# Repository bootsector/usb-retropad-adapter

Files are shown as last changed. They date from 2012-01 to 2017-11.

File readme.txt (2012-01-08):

USB RetroPad Adapter
(c)2011/2012 - Bruno Freitas - bootsector@ig.com.br
See COPYING.TXT for licensing information.

About
-----

USB RetroPad Adapter is a USB port of the Wii RetroPad Adapter. It allows you
to use the following classic controllers in your PC, Mac or PS3:

:. Sega Genesis pad(also supports: Sega Master System, Atari 2600 and others)

:. Nintendo NES pad

:. Super NES pad 

:. Playstation digital pads and Playstation 2 pads

:. Game Cube pad

:. Nintendo 64 pad

USB RetroPad Adapter also comes with handy screw terminal connectors, allowing
you to hook up a homemade arcade control to it and and use it to play your favo-
rite games on your PC or PS3!

How to get it
-------------

USB RetroPad Adapter is Opensource / Open hardware, so you can construct your
PCB, compile the source code, burn the firmware in the micro-controller and
start using it. 

However, there are people who are not familiar with PCB manufacturing process
nor have the skills, or even time, to construct his/her own adapter. For those
people, you are invited to contact me at bootsector@ig.com.br so I can sell
you a ready-to-use adapter! :)

You will also be able to buy it from both http://www.brunofreitas.com/ or
http://www.faiscaefumaca.com.br/

Legal
-----

USB RetroPad Adapter source code (software) is licensed under GPLv3.

USB RetroPad Adapter is open hardware licenced under Creative Commons 
Attribution-ShareAlike 3.0 Unported License. 

Acknowledgements
----------------

Thanks goes out to all people below. Without their work, this project wouldn't
be possible:

:. Roberto Oliveira for all the help with the PCB and "hardware" stuff.

:. Bill Porter for his PS2X Arduino library

:. The Arduino Team

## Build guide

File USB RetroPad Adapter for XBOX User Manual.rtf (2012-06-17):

USB RetroPad Adapter v1.1b for XBOX
User Manual Rev. 1.0 – 06/17/2012

About the USB RetroPad Adapter
USB RetroPad Adapter is an USB joystick adapter that allows you to use the following classic controllers with your PC, Mac and PS3 through the USB port or with your classic XBOX console using an XBOX controller port to USB adapter, with the newly released USB RetroPad Adapter for XBOX:
:. Sega Genesis pad (also supports: Sega Master System, Atari 2600 and others)
:. Nintendo NES pad
:. Super NES pad
:. Playstation digital pads and Playstation 2 pads
:. Game Cube pad
:. Nintendo 64 pad
USB RetroPad Adapter also comes with handy screw terminal connectors (not available in the Lite Edition), allowing you to hook up a homemade arcade control to it and use it to play your favorite games on your PC, PS3 or XBOX!
How to use it
Arcade Mode (not available in the “Lite Edition”):
:. Slide the switch to the “Arcade” position if you want to use the adapter with the screw terminals attached to arcade stick and buttons
:. Each button/stick direction has two wires. Connect one of them to the COMM connector and the other one to any available screw (D0 – D15). Please refer to the reference table showing the screws/joystick button mappings.
Joystick Mode (DB9):
:. Slide the switch to the “DB9” position if you want to use the adapter with your classic controllers.
:. The adapter has native support for Sega Genesis, Master System and Atari 2600 controllers. If you are going to use one of these, just plug them to the DB9 port in the adapter, or;
:. If you are going to use any other joystick, you have to attach the joystick to the appropriate extension cable (sold/built separately), then plug the extension cable into the adapter.
:. Finally, just plug the adapter to your XBOX using an USB printer cable and an XBOX controller port to USB adapter (sold separately).
Button mapping table
XBOX | PS2 | Genesis | Arcade | NES | SNES | GC | N64
D-UP | D-UP | D-UP | D8 | D-UP | D-UP | D-UP | D-UP
D-DOWN | D-DOWN | D-DOWN | D9 | D-DOWN | D-DOWN | D-DOWN | D-DOWN
D-LEFT | D-LEFT | D-LEFT | D10 | D-LEFT | D-LEFT | D-LEFT | D-LEFT
D-RIGHT | D-RIGHT | D-RIGHT | D11 | D-RIGHT | D-RIGHT | D-RIGHT | D-RIGHT
Analog L | Analog L | - | - | - | - | Analog L | Analog Stick
Analog R | Analog R | - | - | - | - | Analog R | C Buttons
X | SQUARE | X | D12 | - | Y | Y | B
A | CROSS | A | D13 | A | B | B | A
B | CIRCLE | B | D15 | B | A | A | -
Y | TRIANGLE | Y | D14 | - | X | X | -
White | L1 | Z | D0 | - | L | - | -
L | L2 | - | D1 | - | - | L | L
Black | R1 | C | D2 | - | R | Z | Z
R | R2 | - | D3 | - | - | R | R
Back | SELECT | MODE | D4 | SELECT | SELECT | - | -
Start | START | START | D5 | START | START | START | START
L3 | L3 | - | D6 | - | - | - | -
R3 | R3 | D-UP + START | D7 | SELECT + START | SELECT + START | D-UP + START | D-UP + START

Additional Information
For more information about the USB RetroPad Adapter, please visit http://www.brunofreitas.com/

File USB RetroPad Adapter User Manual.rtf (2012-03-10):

USB RetroPad Adapter v1.1b
User Manual Rev. 1.0 – 03/10/2012

About the USB RetroPad Adapter
USB RetroPad Adapter is an USB joystick adapter that allows you to use the following classic controllers with your PC, Mac or PS3 through the USB port:
:. Sega Genesis pad (also supports: Sega Master System, Atari 2600 and others)
:. Nintendo NES pad
:. Super NES pad
:. Playstation digital pads and Playstation 2 pads
:. Game Cube pad
:. Nintendo 64 pad
USB RetroPad Adapter also comes with handy screw terminal connectors, allowing you to hook up a homemade arcade control to it and use it to play your favorite games on your PC or PS3!
How to use it
Arcade Mode (not available in the “Lite Edition”):
:. Slide the switch to the “Arcade” position if you want to use the adapter with the screw terminals attached to arcade stick and buttons
:. Each button/stick direction has two wires. Connect one of them to the COMM connector and the other one to any available screw (D0 – D15). Please refer to the reference table showing the screws/joystick button mappings.
Joystick Mode (DB9):
:. Slide the switch to the “DB9” position if you want to use the adapter with your classic controllers.
:. The adapter has native support for Sega Genesis, Master System and Atari 2600 controllers. If you are going to use one of these, just plug them to the DB9 port in the adapter, or;
:. If you are going to use any other joystick, you have to attach the joystick to the appropriate extension cable (sold/built separately), then plug the extension cable into the adapter.
:. Finally, just plug the adapter to your PC, Mac, or PS2 using an USB printer cable (sold separately). No device driver installation is required!
Button mapping table
PS3 | PC | PS2 | Genesis | Arcade | NES | SNES | GC | N64
D-UP | POV-UP | D-UP | - | - | - | - | D-UP | D-UP
D-DOWN | POV-DOWN | D-DOWN | - | - | - | - | D-DOWN | D-DOWN
D-LEFT | POV-LEFT | D-LEFT | - | - | - | - | D-LEFT | D-LEFT
D-RIGHT | POV-RIGHT | D-RIGHT | - | - | - | - | D-RIGHT | D-RIGHT
Analog L | X/Y Axis | Analog L | UP, DOWN, LEFT, RIGHT | D8 (UP), D9 (DOWN), D10 (LEFT), D11 (RIGHT) | UP, DOWN, LEFT, RIGHT | UP, DOWN, LEFT, RIGHT | Analog L | Analog Stick
Analog R | Z Axis | Analog R | - | - | - | - | Analog R | C Buttons
SQUARE | 1 | SQUARE | A | D12 | B | Y | Y | B
CROSS | 2 | CROSS | B | D13 | A | B | B | A
CIRCLE | 3 | CIRCLE | C | D15 | - | A | A | -
TRIANGLE | 4 | TRIANGLE | Y | D14 | - | X | X | -
L1 | 5 | L1 | X | D0 | - | L | L | L
L2 | 6 | L2 | - | D1 | - | - | Z | Z
R1 | 7 | R1 | Z | D2 | - | R | R | R
R2 | 8 | R2 | - | D3 | - | - | - | -
SELECT | 9 | SELECT | MODE | D4 | SELECT | SELECT | - | -
START | 10 | START | START | D5 | START | START | START | START
L3 | 11 | L3 | - | D6 | - | - | - | -
R3 | 12 | R3 | - | - | - | - | - | -
PS Button | 13 | START + SELECT | UP + START | D7 | SELECT + START | SELECT + START | D-UP + START | D-UP + START

Additional Information
For more information about the USB RetroPad Adapter, please visit http://www.brunofreitas.com/

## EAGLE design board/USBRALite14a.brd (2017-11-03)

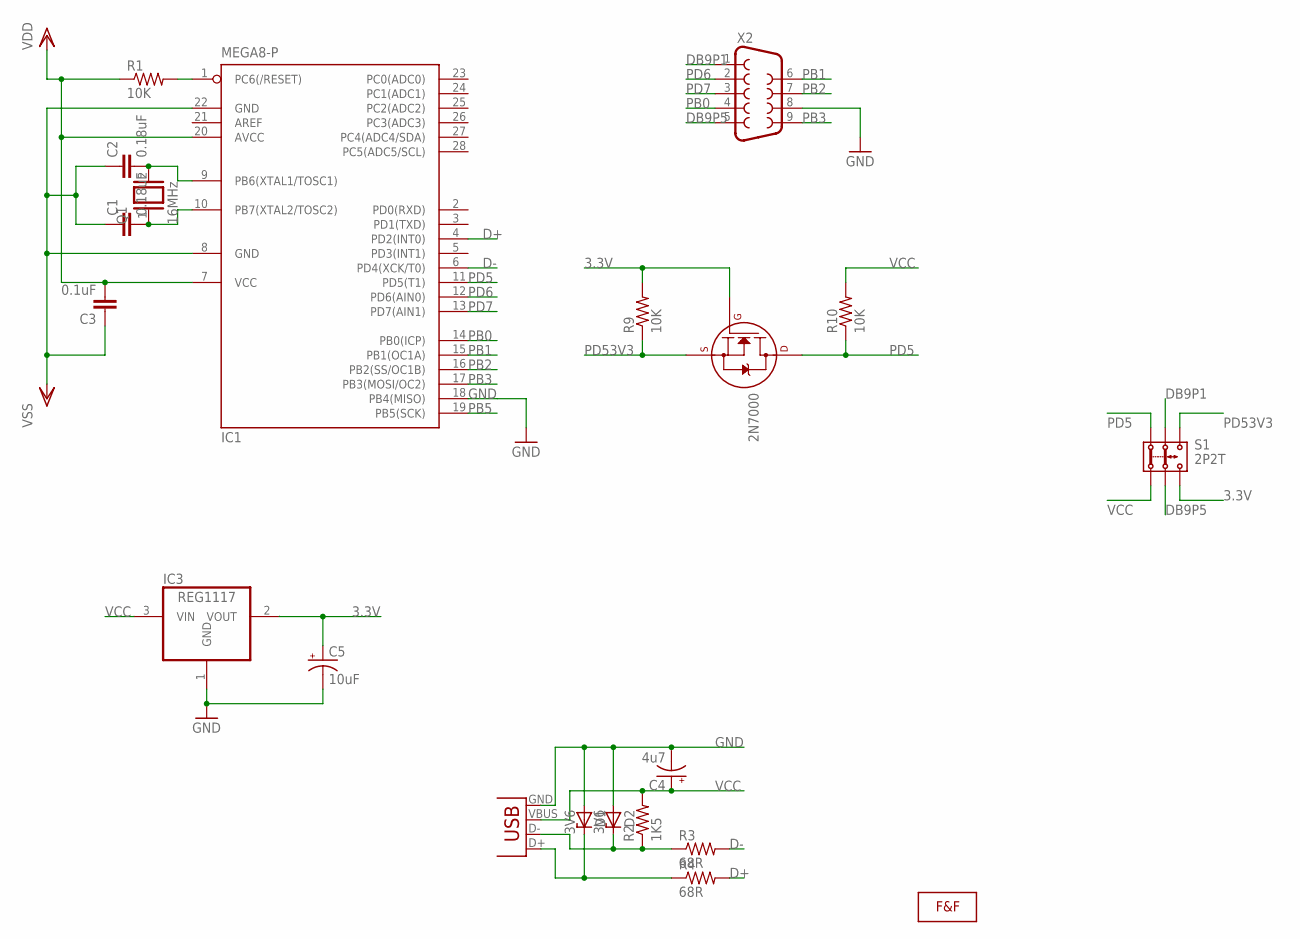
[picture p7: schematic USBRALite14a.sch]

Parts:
2N7000: 2N7000_TO92; TO-92
C1, C2: 0.18uF; C050-024X044
C3: 0.1uF; C050-024X044
C4: 4u7; E2,5-6
C5: 10uF; E2,5-6
D1, D2: 3V6; ZDIO-5
IC1: MEGA8-P; DIL28-3
IC3: REG1117; SOT223
Q1: 16MHz; QS
R1, R9, R10: 10K; 0207/10
R2: 1K5; 0207/10
R3, R4: 68R; 0207/10
S1: 2P2T
U$1: LOGOLOGO_WITHOUT_SMOKE_SMALL; LOGO2_SMALL
X1: USBPTH; USB-B-PTH
X2: DB9MALE; DB9_MALE

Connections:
3.3V: 2N7000.2 (G), C5.+, IC3.2 (VOUT), R9.2, S1.3.2
D+: IC1.4 (PD2(INT0)), R4.2
D-: IC1.6 (PD4(XCK/T0)), R3.2
DB9P1: S1.2.1, X2.1
DB9P5: S1.2.2, X2.5
GND: C1.1, C2.1, C3.1, C4.-, C5.-, D1.A, D2.A, IC1.8 (GND), IC1.18 (PB4(MISO)), IC1.22 (GND), IC3.1 (GND), X1.GND, X2.8
unnamed: IC1.1 (PC6(/RESET)), R1.2
unnamed: C2.2, IC1.9 (PB6(XTAL1/TOSC1)), Q1.2
unnamed: C1.2, IC1.10 (PB7(XTAL2/TOSC2)), Q1.1
unnamed: D1.C, R4.1, X1.D+
unnamed: D2.C, R2.1, R3.1, X1.D-
PB0: IC1.14 (PB0(ICP)), X2.4
PB1: IC1.15 (PB1(OC1A)), X2.6
PB2: IC1.16 (PB2(SS/OC1B)), X2.7
PB3: IC1.17 (PB3(MOSI/OC2)), X2.9
PB5: IC1.19 (PB5(SCK))
PD5: 2N7000.3 (D), IC1.11 (PD5(T1)), R10.1, S1.1.1
PD6: IC1.12 (PD6(AIN0)), X2.2
PD7: IC1.13 (PD7(AIN1)), X2.3
PD53V3: 2N7000.1 (S), R9.1, S1.3.1
VCC: C3.2, C4.+, IC1.7 (VCC), IC1.20 (AVCC), IC3.3 (VIN), R1.1, R2.2, R10.2, S1.1.2, X1.VBUS

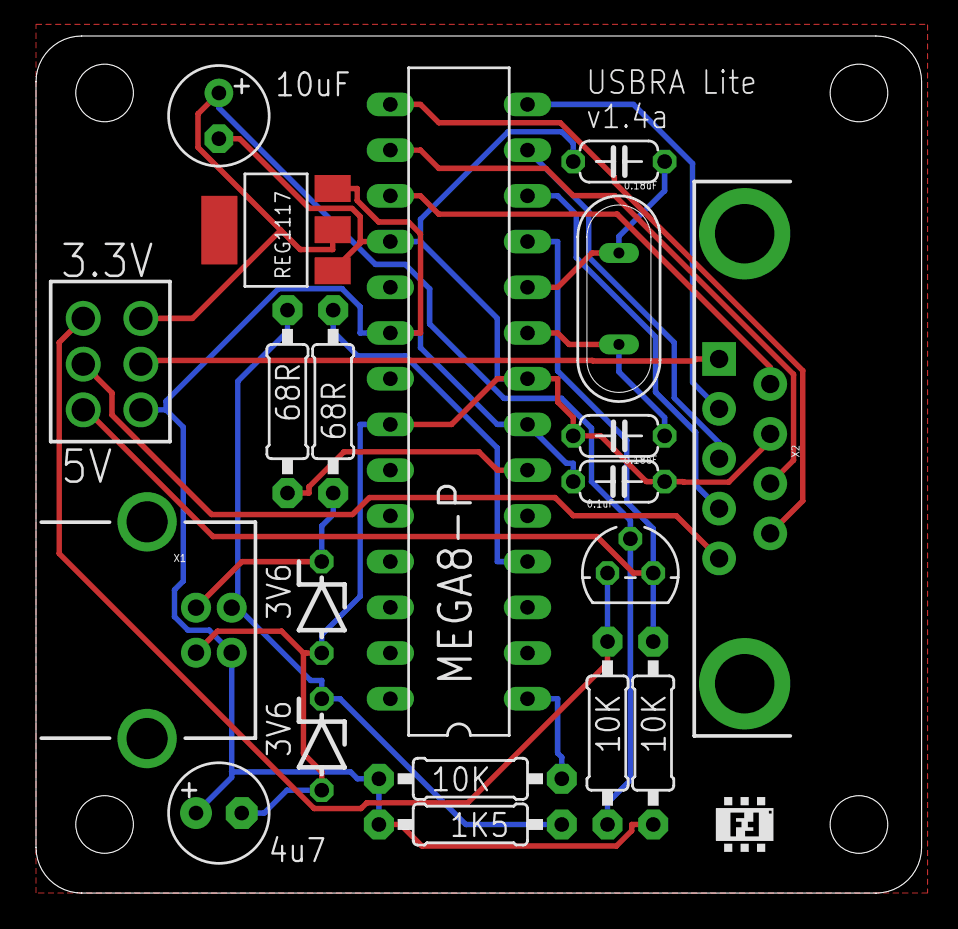
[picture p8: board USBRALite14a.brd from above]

Board: 2 copper layers, 49.2 x 47.6 mm, 21 parts (0 on the bottom side), 20 nets.

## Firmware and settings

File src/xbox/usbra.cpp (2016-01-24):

/*
 * USB RetroPad Adapter - PC/PS3 USB adapter for retro-controllers!
 * Copyright (c) 2012 Bruno Freitas - bruno@brunofreitas.com
 *
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
 * You should have received a copy of the GNU General Public License
 * along with this program.  If not, see <http://www.gnu.org/licenses/>.
 */

#include <WProgram.h>
#include "XBOXPad.h"
#include "../PS2Pad.h"
#include "../genesis.h"
#include "../saturn.h"
#include "../NESPad.h"
#include "../GCPad_16Mhz.h"
#include "../tg16.h"

// Arcade mode detection pin
#define ARCADE_DB9_PIN	12

// Extension cable detection pins
#define DETPIN0 6  // DB9P2
#define DETPIN1	8  // DB9P4
#define DETPIN2	9  // DB9P6
#define DETPIN3	10 // DB9P7
#define DETPIN4	11 // DB9P9

// Possible values (as of today) returned by the detectPad() routine
// Normal pads
#define PAD_ARCADE		-1
#define PAD_GENESIS		0b00111
#define PAD_NES 		0b00110
#define PAD_SNES 		0b00101
#define PAD_PS2 		0b00100
#define PAD_GC	 		0b00011
#define PAD_N64			0b00010
#define PAD_NEOGEO		0b00001
#define PAD_WIICC		0b00000
// Extended pads (uses DB9 pin 4 and/or 2 for identification)
#define PAD_SATURN		0b01111
#define PAD_TG16		0b10111
#define PAD_DFU_DONGLE	0b01110 // Reserved for USBRA DFU dongle

/*
 * This is the new auto-detect function (non jumper based) which detects the extension
 * cable plugged in the DB9 port. It uses grounded pins from DB9 (4, 6, 7 and 9) for
 * the detection.
 *
 *  -1 - Arcade
 * 00111 - Sega Genesis (Default)
 * 00110 - NES
 * 00101 - SNES
 * 00100 - PS2
 * 00011 - Game Cube
 * 00010 - Nintendo 64
 * 00001 - Neo Geo
 * 00000 - Reserved 1
 * 01111 - Sega Saturn
 * 10111 - TurboGrafx 16
 */
int detectPad() {
	int pad;

	// Set pad/arcade detection pins as input, turning pull-ups on
	pinMode(DETPIN0, INPUT);
	digitalWrite(DETPIN0, HIGH);

	pinMode(DETPIN1, INPUT);
	digitalWrite(DETPIN1, HIGH);

	pinMode(DETPIN2, INPUT);
	digitalWrite(DETPIN2, HIGH);

	pinMode(DETPIN3, INPUT);
	digitalWrite(DETPIN3, HIGH);

	pinMode(DETPIN4, INPUT);
	digitalWrite(DETPIN4, HIGH);

	pinMode(ARCADE_DB9_PIN, INPUT);
	digitalWrite(ARCADE_DB9_PIN, HIGH);

	// Check switch for Arcade position
	if(digitalRead(ARCADE_DB9_PIN))
		return PAD_ARCADE;

	pad = (!digitalRead(DETPIN0) << 4) | (!digitalRead(DETPIN1) << 3) | (digitalRead(DETPIN2) << 2) | (digitalRead(DETPIN3) << 1) | (digitalRead(DETPIN4));

	if((pad >> 3) & 0b11) {
		switch(pad) {
		case 0b11011:
		case 0b10111:
			return PAD_TG16;
			break;
		case 0b11111:
		case 0b01111:
			return PAD_SATURN;
			break;
		case 0b11100:
			return PAD_PS2;
			break;
		default:
			return PAD_GENESIS;
			break;
		}
	}

	return (pad & 0b111);
}


void setup() {
	// Initialize USB joystick driver
	xbox_init(true);

	// Delay for waiting XBOX pad to be detected...
	while(!xbox_pad_detected()) {
		xbox_reset_watchdog();
		delayMicroseconds(10000); // 10ms delay
		xbox_send_pad_state();
	}
}

void genesis_loop() {
	int button_data;

	genesis_init();

	for (;;) {

		xbox_reset_watchdog();

		button_data = genesis_read();

		(button_data & GENESIS_UP)    ? bitSet(gamepad_state.digital_buttons, XBOX_DPAD_UP)    : bitClear(gamepad_state.digital_buttons, XBOX_DPAD_UP);
		(button_data & GENESIS_DOWN)  ? bitSet(gamepad_state.digital_buttons, XBOX_DPAD_DOWN)  : bitClear(gamepad_state.digital_buttons, XBOX_DPAD_DOWN);
		(button_data & GENESIS_LEFT)  ? bitSet(gamepad_state.digital_buttons, XBOX_DPAD_LEFT)  : bitClear(gamepad_state.digital_buttons, XBOX_DPAD_LEFT);
		(button_data & GENESIS_RIGHT) ? bitSet(gamepad_state.digital_buttons, XBOX_DPAD_RIGHT) : bitClear(gamepad_state.digital_buttons, XBOX_DPAD_RIGHT);

		gamepad_state.a = ((button_data & GENESIS_A) > 0) * 0xFF;

		gamepad_state.b = ((button_data & GENESIS_B) > 0) * 0xFF;

		gamepad_state.black = ((button_data & GENESIS_C) > 0) * 0xFF;

		gamepad_state.x = ((button_data & GENESIS_X) > 0) * 0xFF;

		gamepad_state.y = ((button_data & GENESIS_Y) > 0) * 0xFF;

		gamepad_state.white = ((button_data & GENESIS_Z) > 0) * 0xFF;

		(button_data & GENESIS_MODE) ? bitSet(gamepad_state.digital_buttons, XBOX_BACK) : bitClear(gamepad_state.digital_buttons, XBOX_BACK);

		(button_data & GENESIS_START) ? bitSet(gamepad_state.digital_buttons, XBOX_START) : bitClear(gamepad_state.digital_buttons, XBOX_START);

		((button_data & GENESIS_UP) && (button_data & GENESIS_START)) ? bitSet(gamepad_state.digital_buttons, XBOX_RIGHT_STICK) : bitClear(gamepad_state.digital_buttons, XBOX_RIGHT_STICK);

		xbox_send_pad_state();
	}
}

void arcade_loop() {
	int button_data;

	NESPad::init(6, 7, 13);

	for (;;) {

		xbox_reset_watchdog();

		button_data = NESPad::read(16);

		(button_data & 0x01) ? bitSet(gamepad_state.digital_buttons, XBOX_DPAD_UP)    : bitClear(gamepad_state.digital_buttons, XBOX_DPAD_UP);
		(button_data & 0x02) ? bitSet(gamepad_state.digital_buttons, XBOX_DPAD_DOWN)  : bitClear(gamepad_state.digital_buttons, XBOX_DPAD_DOWN);
		(button_data & 0x04) ? bitSet(gamepad_state.digital_buttons, XBOX_DPAD_LEFT)  : bitClear(gamepad_state.digital_buttons, XBOX_DPAD_LEFT);
		(button_data & 0x08) ? bitSet(gamepad_state.digital_buttons, XBOX_DPAD_RIGHT) : bitClear(gamepad_state.digital_buttons, XBOX_DPAD_RIGHT);

		gamepad_state.x = ((button_data & 0x10) > 0) * 0xFF;

		gamepad_state.a = ((button_data & 0x20) > 0) * 0xFF;

		gamepad_state.y = ((button_data & 0x40) > 0) * 0xFF;

		gamepad_state.b = ((button_data & 0x80) > 0) * 0xFF;

		gamepad_state.white = ((button_data & 0x100) > 0) * 0xFF;

		gamepad_state.black = ((button_data & 0x200) > 0) * 0xFF;

		gamepad_state.l = ((button_data & 0x400) > 0) * 0xFF;

		gamepad_state.r = ((button_data & 0x800) > 0) * 0xFF;

		((button_data & 0x1000) > 0) ? bitSet(gamepad_state.digital_buttons, XBOX_BACK) : bitClear(gamepad_state.digital_buttons, XBOX_BACK);

		((button_data & 0x2000) > 0) ? bitSet(gamepad_state.digital_buttons, XBOX_START) : bitClear(gamepad_state.digital_buttons, XBOX_START);

		((button_data & 0x4000) > 0) ? bitSet(gamepad_state.digital_buttons, XBOX_LEFT_STICK) : bitClear(gamepad_state.digital_buttons, XBOX_LEFT_STICK);

		((button_data & 0x8000) > 0) ? bitSet(gamepad_state.digital_buttons, XBOX_RIGHT_STICK) : bitClear(gamepad_state.digital_buttons, XBOX_RIGHT_STICK);

		xbox_send_pad_state();
	}
}

void nes_loop() {
	int button_data;

	NESPad::init(5, 6, 7);

	for (;;) {

		xbox_reset_watchdog();

		button_data = NESPad::read(8);

		(button_data & 16)  ? bitSet(gamepad_state.digital_buttons, XBOX_DPAD_UP)    : bitClear(gamepad_state.digital_buttons, XBOX_DPAD_UP);
		(button_data & 32)  ? bitSet(gamepad_state.digital_buttons, XBOX_DPAD_DOWN)  : bitClear(gamepad_state.digital_buttons, XBOX_DPAD_DOWN);
		(button_data & 64)  ? bitSet(gamepad_state.digital_buttons, XBOX_DPAD_LEFT)  : bitClear(gamepad_state.digital_buttons, XBOX_DPAD_LEFT);
		(button_data & 128) ? bitSet(gamepad_state.digital_buttons, XBOX_DPAD_RIGHT) : bitClear(gamepad_state.digital_buttons, XBOX_DPAD_RIGHT);

		gamepad_state.b = ((button_data & 2) > 0) * 0xFF;

		gamepad_state.a = ((button_data & 1) > 0) * 0xFF;

		((button_data & 4) > 0) ? bitSet(gamepad_state.digital_buttons, XBOX_BACK) : bitClear(gamepad_state.digital_buttons, XBOX_BACK);

		((button_data & 8) > 0) ? bitSet(gamepad_state.digital_buttons, XBOX_START) : bitClear(gamepad_state.digital_buttons, XBOX_START);

		((button_data & 4) && (button_data & 8)) ? bitSet(gamepad_state.digital_buttons, XBOX_RIGHT_STICK) : bitClear(gamepad_state.digital_buttons, XBOX_RIGHT_STICK);

		xbox_send_pad_state();
	}
}

void snes_loop() {
	int button_data;

	NESPad::init(5, 6, 7);

	for (;;) {

		xbox_reset_watchdog();

		button_data = NESPad::read(16);

		(button_data & 16)  ? bitSet(gamepad_state.digital_buttons, XBOX_DPAD_UP)    : bitClear(gamepad_state.digital_buttons, XBOX_DPAD_UP);
		(button_data & 32)  ? bitSet(gamepad_state.digital_buttons, XBOX_DPAD_DOWN)  : bitClear(gamepad_state.digital_buttons, XBOX_DPAD_DOWN);
		(button_data & 64)  ? bitSet(gamepad_state.digital_buttons, XBOX_DPAD_LEFT)  : bitClear(gamepad_state.digital_buttons, XBOX_DPAD_LEFT);
		(button_data & 128) ? bitSet(gamepad_state.digital_buttons, XBOX_DPAD_RIGHT) : bitClear(gamepad_state.digital_buttons, XBOX_DPAD_RIGHT);

		gamepad_state.a = ((button_data & 1) > 0) * 0xFF;
		gamepad_state.b = ((button_data & 256) > 0) * 0xFF;
		gamepad_state.x = ((button_data & 2) > 0) * 0xFF;
		gamepad_state.y = ((button_data & 512) > 0) * 0xFF;

		gamepad_state.l = ((button_data & 1024) > 0) * 0xFF;
		gamepad_state.r = ((button_data & 2048) > 0) * 0xFF;

		((button_data & 4) > 0) ? bitSet(gamepad_state.digital_buttons, XBOX_BACK) : bitClear(gamepad_state.digital_buttons, XBOX_BACK);

		((button_data & 8) > 0) ? bitSet(gamepad_state.digital_buttons, XBOX_START) : bitClear(gamepad_state.digital_buttons, XBOX_START);

		((button_data & 4) && (button_data & 8)) ? bitSet(gamepad_state.digital_buttons, XBOX_RIGHT_STICK) : bitClear(gamepad_state.digital_buttons, XBOX_RIGHT_STICK);

		xbox_send_pad_state();
	}
}

void ps2_loop() {
	byte dir = 0;

	while (PS2Pad::init(true)) {
		xbox_reset_watchdog();
		delayMicroseconds(10000); // 10ms delay
		xbox_send_pad_state();
	}

	for (;;) {

		xbox_reset_watchdog();

		PS2Pad::read();

		if(PS2Pad::type() == 0) { // Digital Pad
			gamepad_state.l_x = 0;
			gamepad_state.l_y = 0;
			gamepad_state.r_x = 0;
			gamepad_state.r_y = 0;
		} else {
			gamepad_state.l_x = map(PS2Pad::stick(PSS_LX), 0, 255, -32768, 32767);
			gamepad_state.l_y = map(PS2Pad::stick(PSS_LY), 0, 255, 32767, -32768);
			gamepad_state.r_x = map(PS2Pad::stick(PSS_RX), 0, 255, -32768, 32767);
			gamepad_state.r_y = map(PS2Pad::stick(PSS_RY), 0, 255, 32767, -32768);
		}


		PS2Pad::button(PSB_PAD_UP)    ? bitSet(gamepad_state.digital_buttons, XBOX_DPAD_UP)    : bitClear(gamepad_state.digital_buttons, XBOX_DPAD_UP);
		PS2Pad::button(PSB_PAD_DOWN)  ? bitSet(gamepad_state.digital_buttons, XBOX_DPAD_DOWN)  : bitClear(gamepad_state.digital_buttons, XBOX_DPAD_DOWN);
		PS2Pad::button(PSB_PAD_LEFT)  ? bitSet(gamepad_state.digital_buttons, XBOX_DPAD_LEFT)  : bitClear(gamepad_state.digital_buttons, XBOX_DPAD_LEFT);
		PS2Pad::button(PSB_PAD_RIGHT) ? bitSet(gamepad_state.digital_buttons, XBOX_DPAD_RIGHT) : bitClear(gamepad_state.digital_buttons, XBOX_DPAD_RIGHT);

		gamepad_state.x = PS2Pad::button(PSB_SQUARE) * 0xFF;
		gamepad_state.y = PS2Pad::button(PSB_TRIANGLE) * 0xFF;
		gamepad_state.a = PS2Pad::button(PSB_CROSS) * 0xFF;
		gamepad_state.b = PS2Pad::button(PSB_CIRCLE) * 0xFF;

		PS2Pad::button(PSB_START) ? bitSet(gamepad_state.digital_buttons, XBOX_START) : bitClear(gamepad_state.digital_buttons, XBOX_START);
		PS2Pad::button(PSB_SELECT) ? bitSet(gamepad_state.digital_buttons, XBOX_BACK) : bitClear(gamepad_state.digital_buttons, XBOX_BACK);
		PS2Pad::button(PSB_L3) ? bitSet(gamepad_state.digital_buttons, XBOX_LEFT_STICK) : bitClear(gamepad_state.digital_buttons, XBOX_LEFT_STICK);
		PS2Pad::button(PSB_R3) ? bitSet(gamepad_state.digital_buttons, XBOX_RIGHT_STICK) : bitClear(gamepad_state.digital_buttons, XBOX_RIGHT_STICK);

		gamepad_state.l = PS2Pad::button(PSB_L2) * 0xFF;
		gamepad_state.r = PS2Pad::button(PSB_R2) * 0xFF;

		gamepad_state.white = PS2Pad::button(PSB_L1) * 0xFF;
		gamepad_state.black = PS2Pad::button(PSB_R1) * 0xFF;

		xbox_send_pad_state();
	}
}

void gc_loop() {
	byte *button_data;
	byte dir = 0;

	while(GCPad_init() == 0) {
		xbox_reset_watchdog();
		delayMicroseconds(10000); // 10ms delay
		xbox_send_pad_state();
	}

	for(;;) {

		xbox_reset_watchdog();

		button_data = GCPad_read();

		((button_data[1] & 0x08) > 0) ? bitSet(gamepad_state.digital_buttons, XBOX_DPAD_UP)    : bitClear(gamepad_state.digital_buttons, XBOX_DPAD_UP);
		((button_data[1] & 0x04) > 0) ? bitSet(gamepad_state.digital_buttons, XBOX_DPAD_DOWN)  : bitClear(gamepad_state.digital_buttons, XBOX_DPAD_DOWN);
		((button_data[1] & 0x01) > 0) ? bitSet(gamepad_state.digital_buttons, XBOX_DPAD_LEFT)  : bitClear(gamepad_state.digital_buttons, XBOX_DPAD_LEFT);
		((button_data[1] & 0x02) > 0) ? bitSet(gamepad_state.digital_buttons, XBOX_DPAD_RIGHT) : bitClear(gamepad_state.digital_buttons, XBOX_DPAD_RIGHT);

		gamepad_state.x = ((button_data[0] & 0x08) > 0) * 0xFF;

		gamepad_state.a = ((button_data[0] & 0x02) > 0) * 0xFF;

		gamepad_state.y = ((button_data[0] & 0x04) > 0) * 0xFF;

		gamepad_state.b = ((button_data[0] & 0x01) > 0) * 0xFF;

		((button_data[0] & 0x10) > 0) ? bitSet(gamepad_state.digital_buttons, XBOX_START) : bitClear(gamepad_state.digital_buttons, XBOX_START);

		gamepad_state.l = ((button_data[1] & 0x40) > 0) * 0xFF;

		gamepad_state.r = ((button_data[1] & 0x20) > 0) * 0xFF;

		gamepad_state.black = ((button_data[1] & 0x10) > 0) * 0xFF;

		gamepad_state.l_x = map(button_data[2], 32, 223, -32768, 32767);
		gamepad_state.l_y = map((byte)~button_data[3], 32, 223, 32767, -32768);
		gamepad_state.r_x = map(button_data[4], 32, 223, -32768, 32767);
		gamepad_state.r_y = map((byte)~button_data[5], 32, 223, 32767, -32768);

		((button_data[1] & 0x08) && (button_data[0] & 0x10)) ? bitSet(gamepad_state.digital_buttons, XBOX_RIGHT_STICK) : bitClear(gamepad_state.digital_buttons, XBOX_RIGHT_STICK);

		xbox_send_pad_state();

		delayMicroseconds(5000);
	}
}

void n64_loop() {
	byte *button_data;
	byte dir = 0;
	byte lx, ly;

	while(GCPad_init() == 0) {
		xbox_reset_watchdog();
		delayMicroseconds(10000); // 10ms delay
		xbox_send_pad_state();
	}

	for(;;) {

		xbox_reset_watchdog();

		button_data = N64Pad_read();

		((button_data[0] & 0x08) > 0) ? bitSet(gamepad_state.digital_buttons, XBOX_DPAD_UP)    : bitClear(gamepad_state.digital_buttons, XBOX_DPAD_UP);
		((button_data[0] & 0x04) > 0) ? bitSet(gamepad_state.digital_buttons, XBOX_DPAD_DOWN)  : bitClear(gamepad_state.digital_buttons, XBOX_DPAD_DOWN);
		((button_data[0] & 0x02) > 0) ? bitSet(gamepad_state.digital_buttons, XBOX_DPAD_LEFT)  : bitClear(gamepad_state.digital_buttons, XBOX_DPAD_LEFT);
		((button_data[0] & 0x01) > 0) ? bitSet(gamepad_state.digital_buttons, XBOX_DPAD_RIGHT) : bitClear(gamepad_state.digital_buttons, XBOX_DPAD_RIGHT);

		gamepad_state.x = ((button_data[0] & 0x40) > 0) * 0xFF;

		gamepad_state.a = ((button_data[0] & 0x80) > 0) * 0xFF;

		((button_data[0] & 0x10) > 0) ? bitSet(gamepad_state.digital_buttons, XBOX_START) : bitClear(gamepad_state.digital_buttons, XBOX_START);

		gamepad_state.l = ((button_data[1] & 0x20) > 0) * 0xFF;

		gamepad_state.r = ((button_data[1] & 0x10) > 0) * 0xFF;

		gamepad_state.black = ((button_data[0] & 0x20) > 0) * 0xFF;

		lx = ((button_data[2] >= 128) ? button_data[2] - 128 : button_data[2] + 128);
		ly = ~((button_data[3] >= 128) ? button_data[3] - 128 : button_data[3] + 128);

		gamepad_state.l_x = map(lx, 32, 223, -32768, 32767);
		gamepad_state.l_y = map(ly, 32, 223, 32767, -32768);

		gamepad_state.r_x = 0x00;
		gamepad_state.r_y = 0x00;

		if(button_data[1] & 0x08) { // C Up
			gamepad_state.r_y = 32767;
		} else if(button_data[1] & 0x04) { // C Down
			gamepad_state.r_y = -32768;
		}

		if(button_data[1] & 0x02) { // C Left
			gamepad_state.r_x = -32768;
		} else if(button_data[1] & 0x01) { // C Right
			gamepad_state.r_x = 32767;
		}

		((button_data[0] & 0x08) && (button_data[0] & 0x10)) ? bitSet(gamepad_state.digital_buttons, XBOX_RIGHT_STICK) : bitClear(gamepad_state.digital_buttons, XBOX_RIGHT_STICK);

		xbox_send_pad_state();
	}
}

void neogeo_loop() {
	int button_data;

	NESPad::init(5, 6, 7);

	for (;;) {

		xbox_reset_watchdog();

		button_data = NESPad::read(16);

		(button_data & 0x04)   ? bitSet(gamepad_state.digital_buttons, XBOX_DPAD_UP)    : bitClear(gamepad_state.digital_buttons, XBOX_DPAD_UP);
		(button_data & 0x1000) ? bitSet(gamepad_state.digital_buttons, XBOX_DPAD_DOWN)  : bitClear(gamepad_state.digital_buttons, XBOX_DPAD_DOWN);
		(button_data & 0x02)   ? bitSet(gamepad_state.digital_buttons, XBOX_DPAD_LEFT)  : bitClear(gamepad_state.digital_buttons, XBOX_DPAD_LEFT);
		(button_data & 0x800) ? bitSet(gamepad_state.digital_buttons, XBOX_DPAD_RIGHT) : bitClear(gamepad_state.digital_buttons, XBOX_DPAD_RIGHT);

		gamepad_state.x = ((button_data & 0x8000) > 0) * 0xFF;

		gamepad_state.a = ((button_data & 0x01) > 0) * 0xFF;

		gamepad_state.b = ((button_data & 0x400) > 0) * 0xFF;

		gamepad_state.y = ((button_data & 0x200) > 0) * 0xFF; // D button is also 0x2000

		((button_data & 0x100) > 0)  ? bitSet(gamepad_state.digital_buttons, XBOX_BACK) : bitClear(gamepad_state.digital_buttons, XBOX_BACK);

		((button_data & 0x4000) > 0) ? bitSet(gamepad_state.digital_buttons, XBOX_START) : bitClear(gamepad_state.digital_buttons, XBOX_START);

		((button_data & 0x100) && (button_data & 0x4000)) ? bitSet(gamepad_state.digital_buttons, XBOX_RIGHT_STICK) : bitClear(gamepad_state.digital_buttons, XBOX_RIGHT_STICK);

		xbox_send_pad_state();
	}
}

void saturn_loop() {
	int button_data;

	saturn_init();

	for (;;) {

		xbox_reset_watchdog();

		button_data = saturn_read();

		(button_data & SATURN_UP)    ? bitSet(gamepad_state.digital_buttons, XBOX_DPAD_UP)    : bitClear(gamepad_state.digital_buttons, XBOX_DPAD_UP);
		(button_data & SATURN_DOWN)  ? bitSet(gamepad_state.digital_buttons, XBOX_DPAD_DOWN)  : bitClear(gamepad_state.digital_buttons, XBOX_DPAD_DOWN);
		(button_data & SATURN_LEFT)  ? bitSet(gamepad_state.digital_buttons, XBOX_DPAD_LEFT)  : bitClear(gamepad_state.digital_buttons, XBOX_DPAD_LEFT);
		(button_data & SATURN_RIGHT) ? bitSet(gamepad_state.digital_buttons, XBOX_DPAD_RIGHT) : bitClear(gamepad_state.digital_buttons, XBOX_DPAD_RIGHT);

		gamepad_state.a = ((button_data & SATURN_A) > 0) * 0xFF;

		gamepad_state.b = ((button_data & SATURN_B) > 0) * 0xFF;

		gamepad_state.black = ((button_data & SATURN_C) > 0) * 0xFF;

		gamepad_state.x = ((button_data & SATURN_X) > 0) * 0xFF;

		gamepad_state.y = ((button_data & SATURN_Y) > 0) * 0xFF;

		gamepad_state.white = ((button_data & SATURN_Z) > 0) * 0xFF;
		
		gamepad_state.l = ((button_data & SATURN_L) > 0) * 0xFF;

		gamepad_state.r = ((button_data & SATURN_R) > 0) * 0xFF;

		(button_data & SATURN_START) ? bitSet(gamepad_state.digital_buttons, XBOX_START) : bitClear(gamepad_state.digital_buttons, XBOX_START);

		((button_data & SATURN_UP) && (button_data & SATURN_START)) ? bitSet(gamepad_state.digital_buttons, XBOX_RIGHT_STICK) : bitClear(gamepad_state.digital_buttons, XBOX_RIGHT_STICK);

		xbox_send_pad_state();
	}
}

void tg16_loop(void) {
	int button_data;

	tg16_init();

	for (;;) {
		xbox_reset_watchdog();

		button_data = tg16_read();

		(button_data & (1 << TG16_UP))    ? bitSet(gamepad_state.digital_buttons, XBOX_DPAD_UP)    : bitClear(gamepad_state.digital_buttons, XBOX_DPAD_UP);
		(button_data & (1 << TG16_DOWN))  ? bitSet(gamepad_state.digital_buttons, XBOX_DPAD_DOWN)  : bitClear(gamepad_state.digital_buttons, XBOX_DPAD_DOWN);
		(button_data & (1 << TG16_LEFT))  ? bitSet(gamepad_state.digital_buttons, XBOX_DPAD_LEFT)  : bitClear(gamepad_state.digital_buttons, XBOX_DPAD_LEFT);
		(button_data & (1 << TG16_RIGHT)) ? bitSet(gamepad_state.digital_buttons, XBOX_DPAD_RIGHT) : bitClear(gamepad_state.digital_buttons, XBOX_DPAD_RIGHT);

		gamepad_state.a = ((button_data & (1 << TG16_I)) > 0) * 0xFF;

		gamepad_state.x = ((button_data & (1 << TG16_II)) > 0) * 0xFF;

		(button_data & (1 << TG16_RUN)) ? bitSet(gamepad_state.digital_buttons, XBOX_START) : bitClear(gamepad_state.digital_buttons, XBOX_START);

		(button_data & (1 << TG16_SELECT)) ? bitSet(gamepad_state.digital_buttons, XBOX_BACK) : bitClear(gamepad_state.digital_buttons, XBOX_BACK);

		((button_data & (1 << TG16_RUN)) && (button_data & (1 << TG16_SELECT))) ? bitSet(gamepad_state.digital_buttons, XBOX_RIGHT_STICK) : bitClear(gamepad_state.digital_buttons, XBOX_RIGHT_STICK);

		xbox_send_pad_state();
	}
}


void unsupported_pad(void) {
	for(;;);
}

void loop() {
	switch (detectPad()) {
	case PAD_ARCADE:
		arcade_loop();
		break;
	case PAD_NES:
		nes_loop();
		break;
	case PAD_SNES:
		snes_loop();
		break;
	case PAD_PS2:
		ps2_loop();
		break;
	case PAD_GC:
		gc_loop();
		break;
	case PAD_N64:
		n64_loop();
		break;
	case PAD_NEOGEO:
		neogeo_loop();
		break;
	case PAD_SATURN:
		saturn_loop();
		break;
	case PAD_TG16:
		tg16_loop();
		break;
	case PAD_WIICC:
		unsupported_pad();
		break;
	default:
		genesis_loop();
		break;
	}
}

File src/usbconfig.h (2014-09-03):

/*
* USB RetroPad Adapter - PC/PS3 USB adapter for retro-controllers!
* Copyright (c) 2012 Bruno Freitas - bruno@brunofreitas.com
*
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
* You should have received a copy of the GNU General Public License
* along with this program.  If not, see <http://www.gnu.org/licenses/>.
 */

#ifndef __usbconfig_h_included__
#define __usbconfig_h_included__

/* ---------------------------- Hardware Config ---------------------------- */

#define USB_CFG_IOPORTNAME      D
/* This is the port where the USB bus is connected. When you configure it to
 * "B", the registers PORTB, PINB and DDRB will be used.
 */
#define USB_CFG_DMINUS_BIT      4
/* This is the bit number in USB_CFG_IOPORT where the USB D- line is connected.
 * This may be any bit in the port.
 */
#define USB_CFG_DPLUS_BIT       2
/* This is the bit number in USB_CFG_IOPORT where the USB D+ line is connected.
 * This may be any bit in the port. Please note that D+ must also be connected
 * to interrupt pin INT0! [You can also use other interrupts, see section
 * "Optional MCU Description" below, or you can connect D- to the interrupt, as
 * it is required if you use the USB_COUNT_SOF feature. If you use D- for the
 * interrupt, the USB interrupt will also be triggered at Start-Of-Frame
 * markers every millisecond.]
 */
#define USB_CFG_CLOCK_KHZ       (F_CPU/1000)
/* Clock rate of the AVR in kHz. Legal values are 12000, 12800, 15000, 16000,
 * 16500, 18000 and 20000. The 12.8 MHz and 16.5 MHz versions of the code
 * require no crystal, they tolerate +/- 1% deviation from the nominal
 * frequency. All other rates require a precision of 2000 ppm and thus a
 * crystal!
 * Since F_CPU should be defined to your actual clock rate anyway, you should
 * not need to modify this setting.
 */
#define USB_CFG_CHECK_CRC       0
/* Define this to 1 if you want that the driver checks integrity of incoming
 * data packets (CRC checks). CRC checks cost quite a bit of code size and are
 * currently only available for 18 MHz crystal clock. You must choose
 * USB_CFG_CLOCK_KHZ = 18000 if you enable this option.
 */

/* ----------------------- Optional Hardware Config ------------------------ */

/* #define USB_CFG_PULLUP_IOPORTNAME   D */
/* If you connect the 1.5k pullup resistor from D- to a port pin instead of
 * V+, you can connect and disconnect the device from firmware by calling
 * the macros usbDeviceConnect() and usbDeviceDisconnect() (see usbdrv.h).
 * This constant defines the port on which the pullup resistor is connected.
 */
/* #define USB_CFG_PULLUP_BIT          4 */
/* This constant defines the bit number in USB_CFG_PULLUP_IOPORT (defined
 * above) where the 1.5k pullup resistor is connected. See description
 * above for details.
 */

/* --------------------------- Functional Range ---------------------------- */
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

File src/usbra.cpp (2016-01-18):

/*
 * USB RetroPad Adapter - PC/PS3 USB adapter for retro-controllers!
 * Copyright (c) 2012 Bruno Freitas - bruno@brunofreitas.com
 *
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
 * You should have received a copy of the GNU General Public License
 * along with this program.  If not, see <http://www.gnu.org/licenses/>.
 */

#include <WProgram.h>
#include "USBVirtuaStick.h"
#include "PS2Pad.h"
#include "genesis.h"
#include "saturn.h"
#include "NESPad.h"
#include "GCPad_16Mhz.h"
#include "tg16.h"

// Arcade mode detection pin
#define ARCADE_DB9_PIN	12

// Extension cable detection pins
#define DETPIN0 6  // DB9P2
#define DETPIN1	8  // DB9P4
#define DETPIN2	9  // DB9P6
#define DETPIN3	10 // DB9P7
#define DETPIN4	11 // DB9P9

// Possible values (as of today) returned by the detectPad() routine
// Normal pads
#define PAD_ARCADE		-1
#define PAD_GENESIS		0b00111
#define PAD_NES 		0b00110
#define PAD_SNES 		0b00101
#define PAD_PS2 		0b00100
#define PAD_GC	 		0b00011
#define PAD_N64			0b00010
#define PAD_NEOGEO		0b00001
#define PAD_WIICC		0b00000
// Extended pads (uses DB9 pin 4 and/or 2 for identification)
#define PAD_SATURN		0b01111
#define PAD_TG16		0b10111
#define PAD_DFU_DONGLE	0b01110 // Reserved for USBRA DFU dongle


// Pad directions vector
byte pad_dir[16] = {8, 2, 6, 8, 4, 3, 5, 8, 0, 1, 7, 8, 8, 8, 8, 8};

/*
 * This is the new auto-detect function (non jumper based) which detects the extension
 * cable plugged in the DB9 port. It uses grounded pins from DB9 (4, 6, 7 and 9) for
 * the detection.
 *
 *  -1 - Arcade
 * 00111 - Sega Genesis (Default)
 * 00110 - NES
 * 00101 - SNES
 * 00100 - PS2
 * 00011 - Game Cube
 * 00010 - Nintendo 64
 * 00001 - Neo Geo
 * 00000 - Reserved 1
 * 01111 - Sega Saturn
 * 10111 - TurboGrafx 16
 */
int detectPad() {
	int pad;

	// Set pad/arcade detection pins as input, turning pull-ups on
	pinMode(DETPIN0, INPUT);
	digitalWrite(DETPIN0, HIGH);

	pinMode(DETPIN1, INPUT);
	digitalWrite(DETPIN1, HIGH);

	pinMode(DETPIN2, INPUT);
	digitalWrite(DETPIN2, HIGH);

	pinMode(DETPIN3, INPUT);
	digitalWrite(DETPIN3, HIGH);

	pinMode(DETPIN4, INPUT);
	digitalWrite(DETPIN4, HIGH);

	pinMode(ARCADE_DB9_PIN, INPUT);
	digitalWrite(ARCADE_DB9_PIN, HIGH);

	// Check switch for Arcade position
	if(digitalRead(ARCADE_DB9_PIN))
		return PAD_ARCADE;

	pad = (!digitalRead(DETPIN0) << 4) | (!digitalRead(DETPIN1) << 3) | (digitalRead(DETPIN2) << 2) | (digitalRead(DETPIN3) << 1) | (digitalRead(DETPIN4));

	if((pad >> 3) & 0b11) {
		switch(pad) {
		case 0b11011:
		case 0b10111:
			return PAD_TG16;
			break;
		case 0b11111:
		case 0b01111:
			return PAD_SATURN;
			break;
		case 0b11100:
			return PAD_PS2;
			break;
		default:
			return PAD_GENESIS;
			break;
		}
	}

	return (pad & 0b111);
}

void setup() {
	// Initialize USB joystick driver
	vs_init(true);
}

void genesis_loop() {
	int button_data;

	genesis_init();

	for (;;) {
		vs_reset_watchdog();

		button_data = genesis_read();

		gamepad_state.l_x_axis = 0x80;
		gamepad_state.l_y_axis = 0x80;

		if(button_data & GENESIS_LEFT) {
			gamepad_state.l_x_axis = 0x00;
		} else if (button_data & GENESIS_RIGHT) {
			gamepad_state.l_x_axis = 0xFF;
		}

		if(button_data & GENESIS_UP) {
			gamepad_state.l_y_axis = 0x00;
		} else if (button_data & GENESIS_DOWN) {
			gamepad_state.l_y_axis = 0xFF;
		}

		gamepad_state.square_btn = (button_data & GENESIS_A) > 0;
		gamepad_state.square_axis = (gamepad_state.square_btn ? 0xFF : 0x00);

		gamepad_state.cross_btn = (button_data & GENESIS_B) > 0;
		gamepad_state.cross_axis = (gamepad_state.cross_btn ? 0xFF : 0x00);

		gamepad_state.circle_btn = (button_data & GENESIS_C) > 0;
		gamepad_state.circle_axis = (gamepad_state.circle_btn ? 0xFF : 0x00);

		gamepad_state.l1_btn = (button_data & GENESIS_X) > 0;
		gamepad_state.l1_axis = (gamepad_state.l1_btn ? 0xFF : 0x00);

		gamepad_state.triangle_btn = (button_data & GENESIS_Y) > 0;
		gamepad_state.triangle_axis = (gamepad_state.triangle_btn ? 0xFF : 0x00);

		gamepad_state.r1_btn = (button_data & GENESIS_Z) > 0;
		gamepad_state.r1_axis = (gamepad_state.r1_btn ? 0xFF : 0x00);

		gamepad_state.select_btn = (button_data & GENESIS_MODE) > 0;

		gamepad_state.start_btn = (button_data & GENESIS_START) > 0;

		gamepad_state.ps_btn = (button_data & GENESIS_UP) && (button_data & GENESIS_START);

		vs_send_pad_state();
	}
}

void arcade_loop() {
	int button_data;

	NESPad::init(6, 7, 13);

	for (;;) {
		vs_reset_watchdog();

		button_data = NESPad::read(16);

		gamepad_state.l_x_axis = 0x80;
		gamepad_state.l_y_axis = 0x80;

		if(button_data & 0x01) {
			gamepad_state.l_y_axis = 0x00;
		} else if (button_data & 0x02) {
			gamepad_state.l_y_axis = 0xFF;
		}


		if(button_data & 0x04) {
			gamepad_state.l_x_axis = 0x00;
		} else if (button_data & 0x08) {
			gamepad_state.l_x_axis = 0xFF;
		}

		gamepad_state.square_btn = (button_data & 0x10) > 0;
		gamepad_state.square_axis = (gamepad_state.square_btn ? 0xFF : 0x00);

		gamepad_state.cross_btn = (button_data & 0x20) > 0;
		gamepad_state.cross_axis = (gamepad_state.cross_btn ? 0xFF : 0x00);

		gamepad_state.triangle_btn = (button_data & 0x40) > 0;
		gamepad_state.triangle_axis = (gamepad_state.triangle_btn ? 0xFF : 0x00);

		gamepad_state.circle_btn = (button_data & 0x80) > 0;
		gamepad_state.circle_axis = (gamepad_state.circle_btn ? 0xFF : 0x00);

		gamepad_state.l1_btn = (button_data & 0x100) > 0;
		gamepad_state.l1_axis = (gamepad_state.l1_btn ? 0xFF : 0x00);

		gamepad_state.r1_btn = (button_data & 0x200) > 0;
		gamepad_state.r1_axis = (gamepad_state.r1_btn ? 0xFF : 0x00);

		gamepad_state.l2_btn = (button_data & 0x400) > 0;
		gamepad_state.l2_axis = (gamepad_state.l2_btn ? 0xFF : 0x00);

		gamepad_state.r2_btn = (button_data & 0x800) > 0;
		gamepad_state.r2_axis = (gamepad_state.r2_btn ? 0xFF : 0x00);

		gamepad_state.select_btn = (button_data & 0x1000) > 0;

		gamepad_state.start_btn = (button_data & 0x2000) > 0;

		gamepad_state.l3_btn = (button_data & 0x4000) > 0;

		gamepad_state.ps_btn = (button_data & 0x8000) > 0;

		vs_send_pad_state();
	}
}

void nes_loop() {
	int button_data;

	NESPad::init(5, 6, 7);

	for (;;) {
		vs_reset_watchdog();

		button_data = NESPad::read(8);

		gamepad_state.l_x_axis = 0x80;
		gamepad_state.l_y_axis = 0x80;

		if(button_data & 64) {
			gamepad_state.l_x_axis = 0x00;
		} else if (button_data & 128) {
			gamepad_state.l_x_axis = 0xFF;
		}

		if(button_data & 16) {
			gamepad_state.l_y_axis = 0x00;
		} else if (button_data & 32) {
			gamepad_state.l_y_axis = 0xFF;
		}

		gamepad_state.square_btn = (button_data & 2) > 0;
		gamepad_state.square_axis = (gamepad_state.square_btn ? 0xFF : 0x00);

		gamepad_state.cross_btn = (button_data & 1) > 0;
		gamepad_state.cross_axis = (gamepad_state.cross_btn ? 0xFF : 0x00);

		gamepad_state.select_btn = (button_data & 4) > 0;

		gamepad_state.start_btn = (button_data & 8) > 0;

		gamepad_state.ps_btn = (button_data & 4) && (button_data & 8); // SELECT + START = PS Button

		vs_send_pad_state();
	}
}
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

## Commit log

2012-01-08 Uploaded board image.
2012-01-09 Updated board files to Rev.1.
2012-01-09 Added 68R resistors value to schematics.
2012-01-10 Added svg file for acrylic laser cut.
2012-01-11 - DB9 pins 1 and 5 had voltage dropped to 3.3V in order to respect N64 and GC pads voltage. It shouldn't bring problems to other pads. To be tested...
    - 4021 arrangement data pin changed to a separate pin on atmega.
2012-01-11 Changed NESPad class so it allows defining clock, latch and data pins via constructor, so it works with a different data pin for the Arcade shiftin.
    Updated licensing info in some files.
2012-01-12 Corrected clock and latch pins for Arcade protocol.
    [usbra.cpp]
2012-01-12 Fixed schematics and board files with proper MOSFET resistor (2N7000) for voltage shift between atmega (5V) and N64/GC contollers (3.4V).
    Corrected DB9/Arcade selection code.
    [usbra.cpp]
2012-01-14 Added clearance for PCB standoffs. Repositioned LM137 as well for easier bending.
2012-01-14 Added top lasercut SVG.
2012-01-16 Added support for L3 and R3 buttons.
2012-01-16 Last remaining button from arcade_loop function set to L3.
2012-02-03 Disabled BOD in the uC fuses. Tries to initialize PS2/PSX pad only once.
2012-02-03 Reverted fuses config.
2012-02-04 Added USB RetroPad Adapter Lite 1.0 board/acrylic files.
2012-02-05 Disabled Timer 0 Overflow Interrupt inside vs_init() function. This interrupt is enabled by Arduino's init() function and it was making the PS3 to have dificulties trying to detect the adapter.
2012-02-06 Now that Timer0 overflow interrupt is disabled, it's important to NOT use Arduino's millis(), delay() and micros() functions, as they rely on that interrupt to work. PSX2 library seems to work fine a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
2012-02-06 Stopped using Bill Porter's PSX/PS2 lib because it relies on Arduino timer functions. Now using a much more simplified, yet VERY functional library, that don't make use of millis(), micros() or delay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
2012-02-08 Reverted back to Bill Porter's PSX/PS2 lib and changed it to not use delay() or millis().
    [genesis.cpp, usbra.cpp]
2012-02-28 Updating analog axis values for square, circle, cross, triangle, l1, l2, r1, r2 buttons when necessary. Thanks Alan Chatham for the heads up!
2012-03-10 Corrected Arcade reading routine. Updated manual with correct Arcade pin/button mappings.
    [usbra.cpp]
2012-03-11 Commited board v1.2 files. No voltage regulator for N64/GC on-board anymore. There will be a new attachment board for regulating voltage for those joysticks.
2012-03-11 Updated 1.2 board eagle files. Added N64/GC voltage regulator board circuit.
2012-04-09 Commited new boards revision (1.3)
2012-04-27 GC and N64 driver now checks if a controller is not inserted and updates USB bus in case of controller timeout.
2012-05-05 Committed board revision 1.3a.
2012-05-10 Fixed arduino core so it compiles under newest avr-glibc versions (http://code.google.com/p/arduino/issues/detail?id=604).
2012-05-27 Added asm version of GC/N64 driver just in case future compiler versions mess with instructions (optimizations, etc...) in a way the time sensitive routines get off. Whenever that happens, use the as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
2012-05-28 Renamed GC/N64 driver asm code directory.
2012-06-09 :. Added one more pin to the pad detection routines (pin 4 - DB9) :. Added support for Sega Saturn pads (to be tested)
2012-06-09 DB9 pin 4 can't be used as a detection pin for Saturn pads because it may confuse PS2 pad detection (PS2 uses DB9 pin 4 as CLK signal).
    So, in order to get Sega Saturn pad support, you'll lose
    Sega Genesis/Master System/Atari, as Saturn pads uses almost as much
    pins from DB9 as Sega Genesis pads.
    So the default pad will be either Sega Genesis or Sega Saturn, and this
    is defined at compile time by setting the SATURN definition in the
    Makefile.
2012-06-09 Rewrite of the detectPad() routine so it takes care of PS2 pads/DB9 pin 4 usage. Now this should support Sega Saturn pads without losing support for Genesis pads.
2012-06-10 Fixed sega saturn controller extension diagram. Also fixed/improved some stuff in the sega saturn pad reading code.
    [saturn.cpp]
2012-06-10 Changed digital pins handling functions from the "Fast" ones to the ordinary ones, as they were leading to wrong readings inside the pad detection routine.
    [usbra.cpp]
2012-06-16 XBOX driver code cleanup
2012-06-26 Using a new PS2 pad driver (smaller one)
2012-06-30 Fixed NeoGeo pad support.
    [usbra.cpp]
2012-06-30 NeoGeo pad support was broken for XBOX. Fixed.
    [usbra.cpp]
2012-07-01 DFU condition has changed from checking DB9 pin 1 to both DB9 pins 4 and 9 (grounded).
2012-07-26 :. Improved PS2 driver :. Improved XBOX Pad driver
2012-07-27 PS2 pad driver tweak. Enabled watchdog for PC/Mac/PS3 USB.
2012-07-28 PS2 Pad driver: reverted to more aggressive interrupt disable. This makes the PS2 controller more responsive on XBOX (USB RetroPad Adapter). This can be disable so it still works on Wii RetroPad Adap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
    [PS2Pad.cpp, PS2Pad.h, usbra.cpp]
2012-09-04 PS2 pad driver now detects analog mode during init.
2012-09-05 Treating Wii Classic Controller extension cable.
2012-09-29 Fixed HOME button triggering condition (Master System pad Button 2 reports like C + START buttons).
    [usbra.cpp]
2012-09-30 Fixed Sega Genesis controller driver so it works fine with Sega Master System, Atari 2600 and compatibles.
    [genesis.cpp, usbra.cpp]
2013-01-03 Improved GCPad driver timing by making core read/write functions inline and adjusted the delay for the reading function.
2013-01-03 Added a 6ms delay between GC pad reads so don't get the controller too much stressed. Official games poll the controller using that interval.
    [usbra.cpp]
2013-04-21 Added TG16 extension cable schematics
2013-04-21 Fixed extension detection routine
    [usbra.cpp]
2016-01-18 Fixed Arduino map() function. Fixed analog ranges for GC and N64 pads
    [usbra.cpp]
2016-01-24 Fixed analog range for GC pad on XBOX
    [usbra.cpp]
2017-10-28 Added USB RetroPad Adapter v1.4 Lite PCB and gerber files - Using SMD based 3.3v voltage regulator
    [USBRALite14.brd, USBRALite14.sch]
2017-11-03 Updated PCB to v1.4a with thicker traces
    [USBRALite14a.brd, USBRALite14a.sch]
2017-11-25 Fixed Saturn Hori Arcade Stick compatibility
    [saturn.cpp]
2017-11-27 atmega168 fuses config fix

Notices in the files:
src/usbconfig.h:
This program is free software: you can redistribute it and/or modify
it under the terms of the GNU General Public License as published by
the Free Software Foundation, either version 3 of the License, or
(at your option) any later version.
